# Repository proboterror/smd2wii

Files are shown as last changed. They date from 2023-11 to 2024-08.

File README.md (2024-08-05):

# SMD2Wii
SMD2Wii - adapter for Sega Mega Drive controller to Wii remote.

Adapter emulates Wii Classic Controller with Sega Mega Drive / Genesis 3/6-button controller and can be used with homebrew emulators like Genesis Plus GX and selected Wii Virtual Console Games.<br>
Work not confirmed for NES Classic Mini / SNES Classic Mini.

The goal is to connect SMD 6-button controller to Wii as cheap and simple as possible.<br>
For NES / SNES emulators excellent Nintendo Classic Mini Controller / Nintendo SNES Classic Mini Controller suggested.

Project based on Cluster's [nes2wii](https://github.com/ClusterM/nes2wii) project with following changes:
* Controller replaced with simpler / cheaper ATmega8A
* Deleted all other platforms and second SMD pad support from source code and schematics
* New smaller PCB
* Fixed SMD 6-button pad state query errors
* KiCad 7.0 schematic and PCB sources added

## Schematics

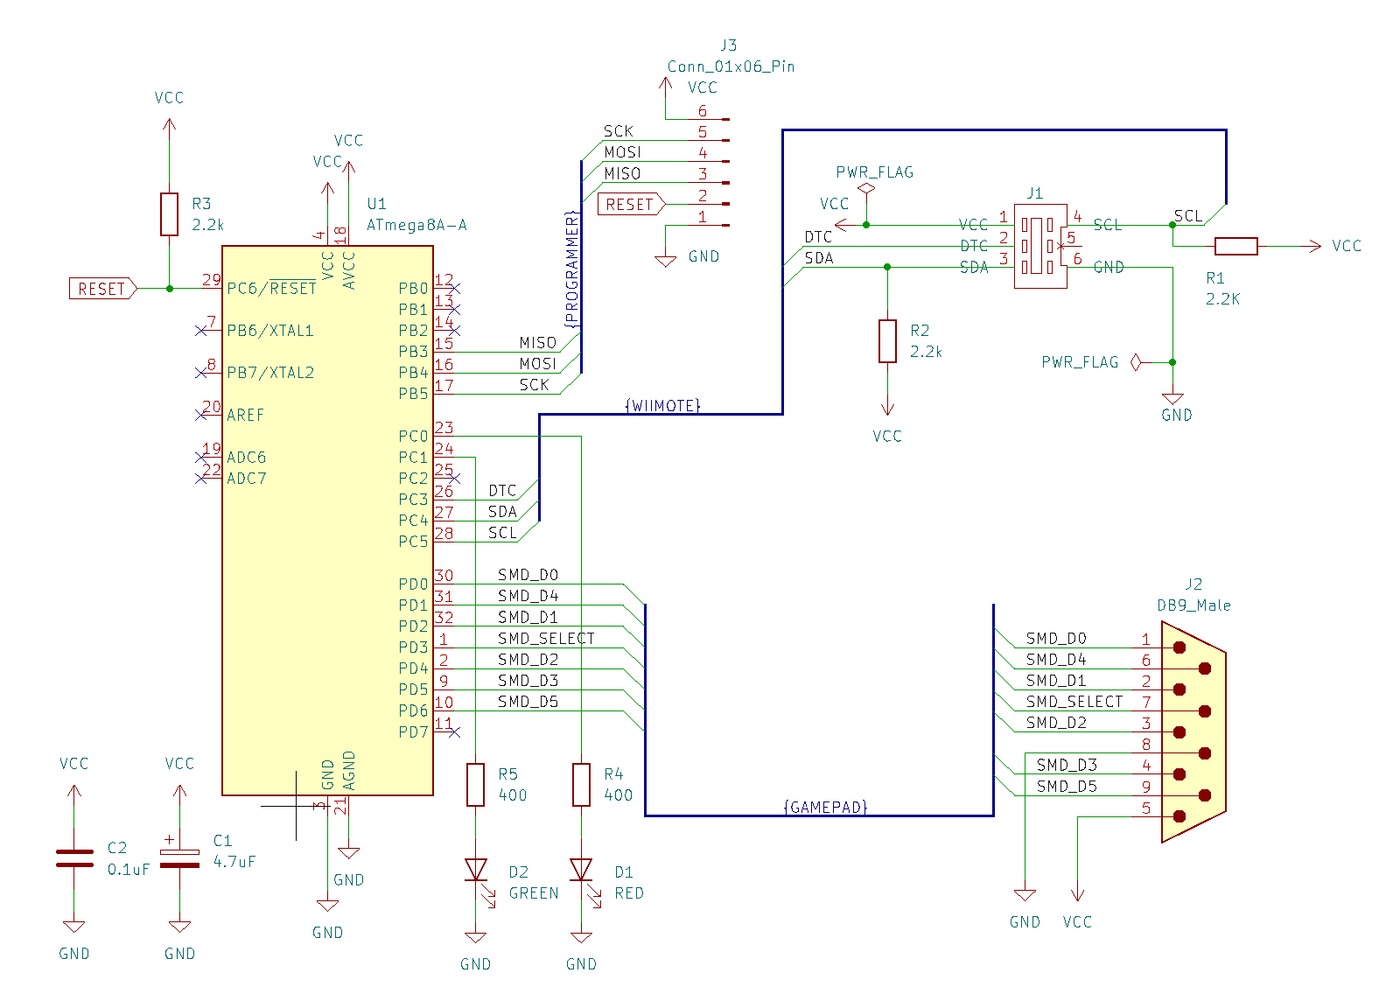
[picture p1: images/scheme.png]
Schematics


Board:<br>
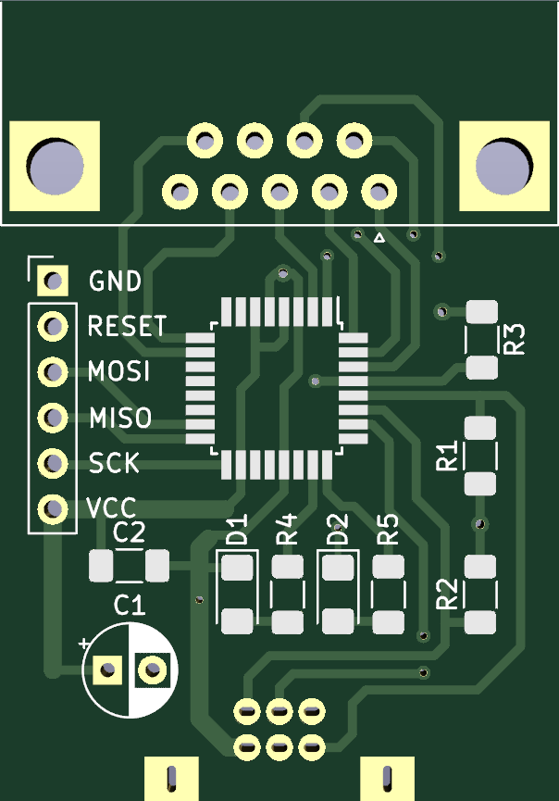
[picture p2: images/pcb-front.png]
Front
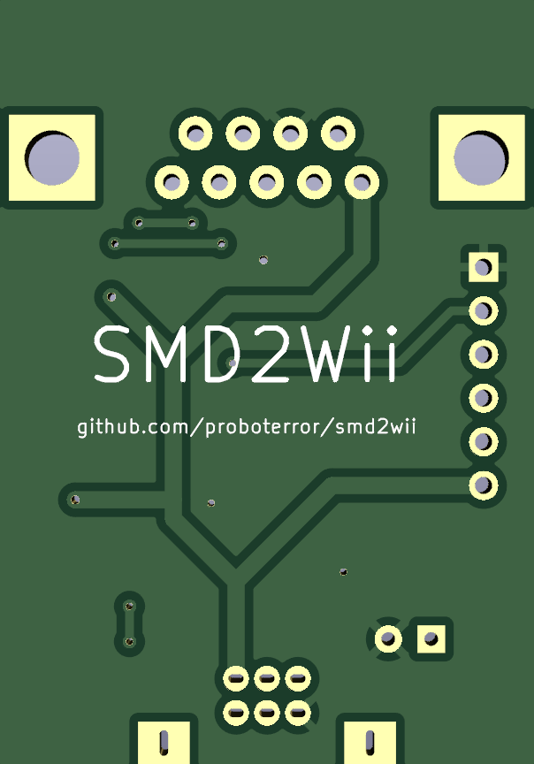
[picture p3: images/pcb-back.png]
Back


Assembled board preview without Wiimote connector:
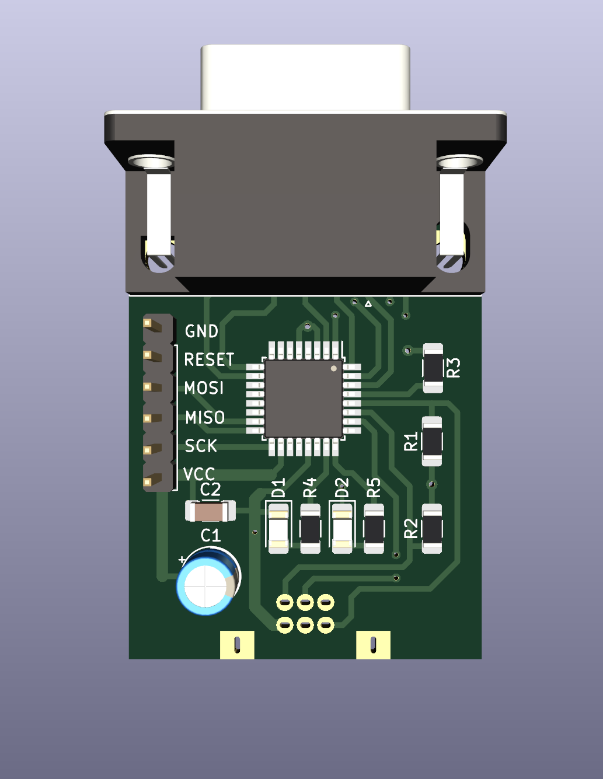
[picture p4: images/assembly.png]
Assembly


## Fuses 

[Bits configuration](images/fuses.png)

* Low fuse: 0xC4
* High fuse: 0xD9

# Compiling from source
Windows:<br>
Install WinAVR-20100110-install.exe<br>
make all<br>

CH341A programmer and NeoProgrammer V2.2 software can be used for firmware .hex flashing.

## Tested with

* ATmega8A-U, 8MHz
* Third party 6-buttons Sega Mega Drive controller with Mode button ("Retro Genesis 16 Bit ACSg11")
* Software: Genesis Plus GX, FCE Ultra GX, WiiMednafen, RetroArch

## Modes

There are three modes for controller d-pad:
* Mode #1 - d-pad works as left analog stick and d-pad on classic controller at the same time
* Mode #2 - d-pad works as left analog stick only
* Mode #3 - d-pad works as d-pad only

Mode 1 selected by default.

You can hold Start+B+C for a few seconds to change mode. Red led will blink 1/2/3 times indicating new mode.

## Bill of materials
* ATMEGA8A-U TQFP32
* DB9 PCB Connector Angle (DSUB-9 Male Horizontal P2.77x2.84mm Edge Pin Offset 7.70mm Mounting Holes Offset 9.12mm)
* Wii controller 6 Pin 90 degree male connector
* SMD 1206 Resistor 2.2k(222) x3
* SMD 1206 Capacitor 0.1(104) uF x1
* (only for programming) Connector PinHeader 2.54mm 1x06 Vertical
* (optional) Electrolytic Capacitor Radial D5.0mm P2.50mm 4.7 uF
* (optional) SMD 1206 Resistor 400 Ohm x2
* (optional) SMD 1206 LED Red x1
* (optional) SMD 1206 LED Green x1

## Notes

### About delays and interrupts
SMD controller polled every 5 ms. Wiimote classic controller query interrupt disabled during the poll (not sure if interrupt is delayed or cancelled).<br>
Worst case scenario additional input delay is about 5-6 ms (or one frame).<br>
Current code:
```c++
void gamepads_query()
{
	_delay_ms(5); // Must be >= 3 to give 6-button controller time to reset

	cli(); // Disable wiimote poll interrupt

	// 8 iterations for read controller state.
	for (b = 0; b < 8; b++)
	{
		_delay_us(2); // Short delay to stabilise outputs in controller.
		...read pad pins
		...invert SELECT pin
	}

	sei(); // Enable interrupt

```
See [gamepads.c](gamepads.c) code comments for more details.
### Buttons mapping
Classic controller to SMD buttons mapping:
```c++
a = smd.c;
b = smd.b;
x = smd.y;
y = smd.a;
l = smd.x;
r = smd.z;
select = smd.mode;
start = smd.start;
```

## Author(s)

Original firmware and schematics for ATMEGA16A:<br>
Alexey 'Cluster' Avdyukhin [https://github.com/ClusterM](https://github.com/ClusterM)<br>
[https://github.com/ClusterM/nes2wii](https://github.com/ClusterM/nes2wii)

Sega MD 6-buttons query code and documentation:<br>
[https://github.com/MickGyver/DaemonBite-Retro-Controllers-USB](https://github.com/MickGyver/DaemonBite-Retro-Controllers-USB)<br>
[https://github.com/jonthysell/SegaController](https://github.com/jonthysell/SegaController)

SMD2Wii modifications:<br>
[probotector](https://github.com/proboterror)

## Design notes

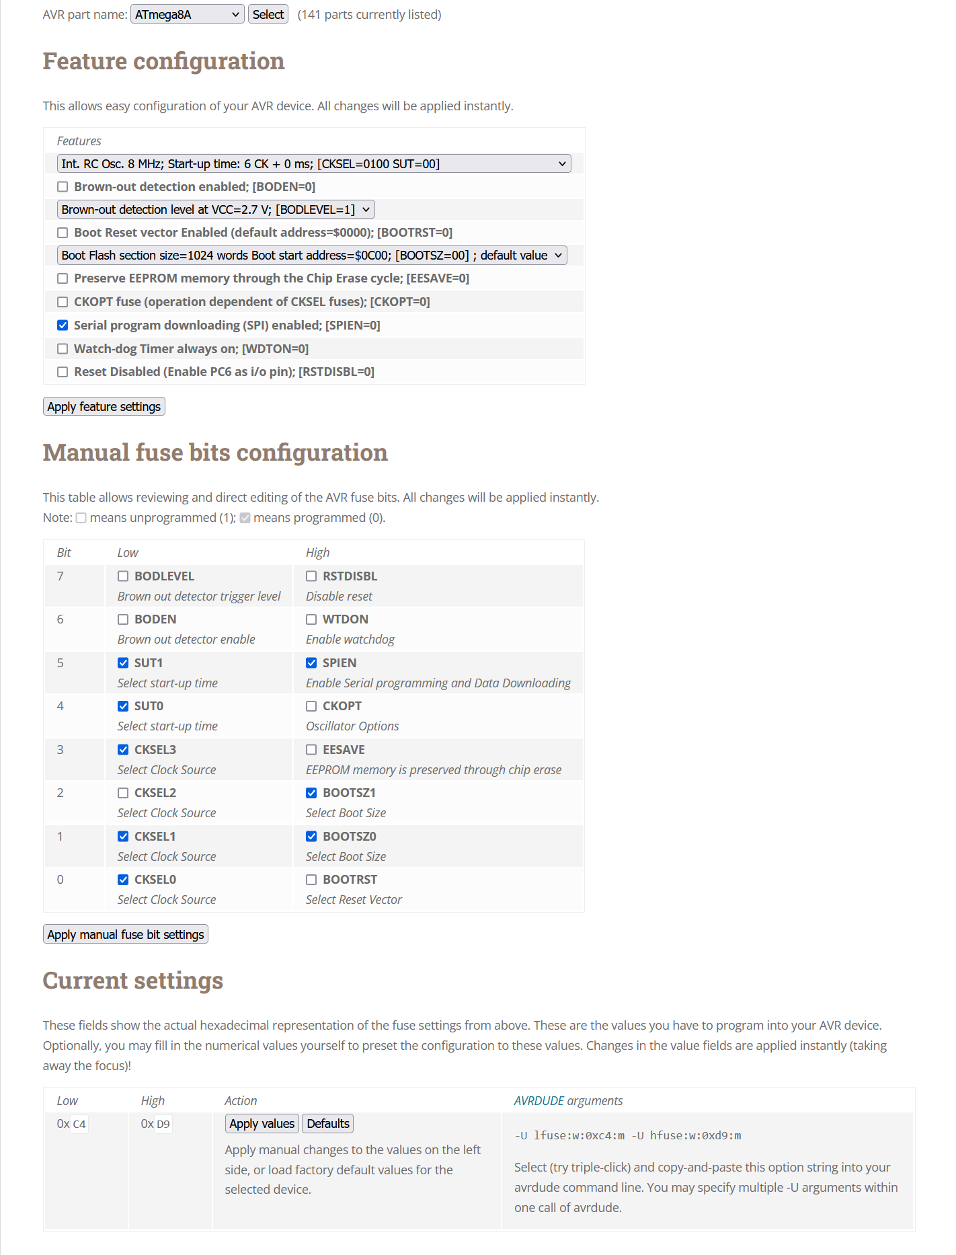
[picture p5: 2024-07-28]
images/fuses.png

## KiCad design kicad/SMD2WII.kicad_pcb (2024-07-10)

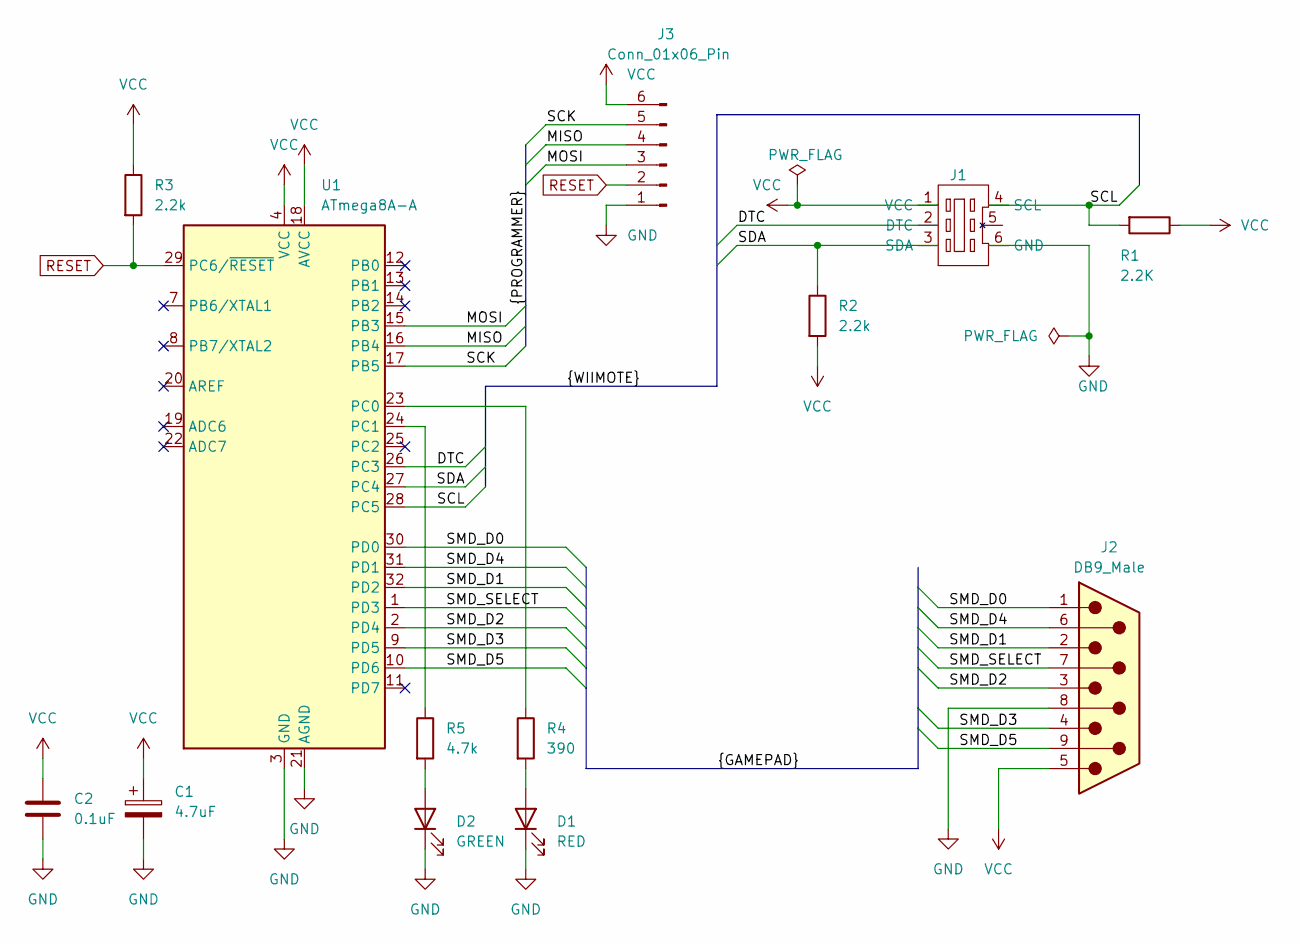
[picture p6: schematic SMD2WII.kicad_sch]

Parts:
C1: 4.7uF; CP_Radial_D5.0mm_P2.50mm
C2: 0.1uF; C_1206_3216Metric_Pad1.33x1.80mm_HandSolder
D1: RED; LED_1206_3216Metric_Pad1.42x1.75mm_HandSolder
D2: GREEN; LED_1206_3216Metric_Pad1.42x1.75mm_HandSolder
J1: Wii_Nunchuck_Connector
J2: DB9_Male; DSUB-9_Male_Horizontal_P2.77x2.84mm_EdgePinOffset7.70mm_Hou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
J3: Conn_01x06_Pin; PinHeader_1x06_P2.54mm_Vertical
R1: 2.2K; R_1206_3216Metric_Pad1.30x1.75mm_HandSolder
R2, R3: 2.2k; R_1206_3216Metric_Pad1.30x1.75mm_HandSolder
R4: 390; R_1206_3216Metric_Pad1.30x1.75mm_HandSolder
R5: 4.7k; R_1206_3216Metric_Pad1.30x1.75mm_HandSolder
U1: ATmega8A-A; TQFP-32_7x7mm_P0.8mm

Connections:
/DTC: J1.2 (DTC), U1.26 (PC3)
/MISO: J3.4, U1.16 (PB4)
/MOSI: J3.3, U1.15 (PB3)
/SCK: J3.5, U1.17 (PB5)
/SCL: J1.4 (SCL), R1.2, U1.28 (PC5)
/SDA: J1.3 (SDA), R2.1, U1.27 (PC4)
/SMD_D0: J2.1, U1.30 (PD0)
/SMD_D1: J2.2, U1.32 (PD2)
/SMD_D2: J2.3, U1.2 (PD4)
/SMD_D3: J2.4, U1.9 (PD5)
/SMD_D4: J2.6, U1.31 (PD1)
/SMD_D5: J2.9, U1.10 (PD6)
/SMD_SELECT: J2.7, U1.1 (PD3)
GND: C1.2, C2.2, D1.1 (K), D2.1 (K), J1.6 (GND), J2.8, J3.1, U1.3 (GND), U1.5 (GND), U1.21 (AGND)
unnamed: D1.2 (A), R4.2
unnamed: D2.2 (A), R5.2
unnamed: R4.1, U1.23 (PC0)
unnamed: R5.1, U1.24 (PC1)
RESET: J3.2, R3.2, U1.29 (PC6/~RESET)
VCC: C1.1, C2.1, J1.1 (VCC), J2.5, J3.6, R1.1, R2.2, R3.1, U1.4 (VCC), U1.6 (VCC), U1.18 (AVCC)

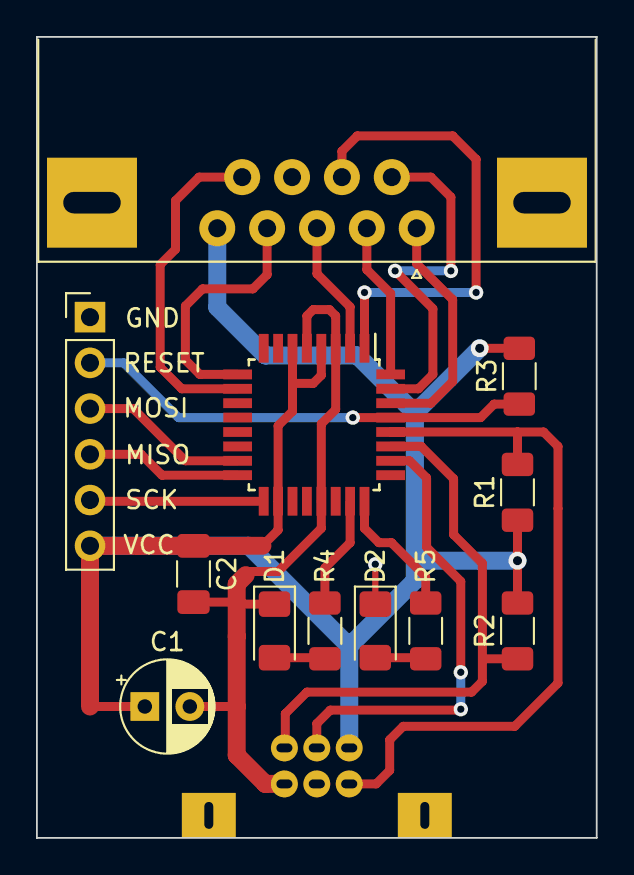
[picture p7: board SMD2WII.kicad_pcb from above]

Board: 2 copper layers, 31.1 x 44.5 mm, 13 parts (0 on the bottom side), 20 nets.

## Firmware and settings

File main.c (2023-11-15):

#include "nes2wii.h"
#include "defines.h"
#include <util/delay.h>
#include <avr/eeprom.h>
#include <avr/wdt.h>
#include <inttypes.h>
#include "wiimote.h"
#include "gamepads.h"

// classic controller id
const unsigned char classic_controller_id[6] = {0x00, 0x00, 0xA4, 0x20, 0x01, 0x01};

volatile int8_t jx = 0, jy = 0, rx = 0, ry = 0;
volatile uint8_t tl = 0, tr = 0;
volatile uint8_t left = 0, right = 0, up = 0, down = 0, a = 0, b = 0, x = 0, y = 0, 
				select = 0, start = 0, home = 0, l = 0, r = 0, zl = 0, zr = 0;
volatile uint8_t connected = 0;
volatile uint8_t dpad_mode = DPAD_MODE_BOTH;

// calibration data
const unsigned char cal_data[32] = {
	0x00, 0x00, 0x00, 0x00,
	0x00, 0x00, 0x00, 0x00,
	0x00, 0x00, 0x00, 0x00,
	0x00, 0x00, 0x00, 0x00,
	0x00, 0x00, 0x00, 0x00,
	0x00, 0x00, 0x00, 0x00,
	0x00, 0x00, 0x00, 0x00,
	0x00, 0x00, 0x00, 0x00
};

void wiimote_query()
{
	wdt_reset();
	if (connected < 2)
	{
		connected = 2;
		RED_ON;
	}
	unsigned char but_dat[8]; // struct containing button data
	if (twi_reg[0xFE] == 1) // data format
	{
		but_dat[0] = 0b00000000; // RX<4:3>	LX<5:0>
		but_dat[1] = 0b00000000; // RX<2:1>	LY<5:0>
		but_dat[2] = 0b00000000; // RX<0>	LT<4:3>	RY<4:0>
		but_dat[3] = 0b00000000; // LT<2:0>	RT<4:0>
		but_dat[4] = 0b11111111; // BDR	BDD	BLT	B-	BH	B+	BRT	 1
		but_dat[5] = 0b11111111; // BZL	BB	BY	BA	BX	BZR	BDL	BDU
		but_dat[6] = 0;
		but_dat[7] = 0;
		
		but_dat[0] |= (jx / 4 + 0x20) & 0x3F;
		but_dat[1] |= (jy / -4 + 0x20) & 0x3F;
		but_dat[0] |= ((rx / 8 + 0x10) & 0x18) << 3;
		but_dat[1] |= ((rx / 8 + 0x10) & 0x06) << 5;
		but_dat[2] |= ((rx / 8 + 0x10) & 0x01) << 7;
		but_dat[2] |= (ry / -8 + 0x10) & 0x1F;
		but_dat[2] |= ((tl / 8) & 0x18) << 2;
		but_dat[3] |= ((tl / 8) & 0x07) << 5;
		but_dat[3] |= (tr / 8) & 0x1F;

		if (right) but_dat[4] &= ~(1<<7);
		if (down) but_dat[4] &= ~(1<<6);
		if (l) but_dat[4] &= ~(1<<5);
		if (select) but_dat[4] &= ~(1<<4);
		if (home) but_dat[4] &= ~(1<<3);
		if (start) but_dat[4] &= ~(1<<2);
		if (r) but_dat[4] &= ~(1<<1);
		
		if (zl) but_dat[5] &= ~(1<<7);
		if (b) but_dat[5] &= ~(1<<6);
		if (y) but_dat[5] &= ~(1<<5);
		if (a) but_dat[5] &= ~(1<<4);
		if (x) but_dat[5] &= ~(1<<3);
		if (zr) but_dat[5] &= ~(1<<2);
		if (left) but_dat[5] &= ~(1<<1);
		if (up) but_dat[5] &= ~(1<<0);
		
		but_dat[6] = 0;
		but_dat[7] = 0;
		
		if (((but_dat[4] & 0xFE) == 0xFE) && (but_dat[5] == 0xFF) && 
			(ABS(jx) < DEAD_ZONE) && (ABS(jy) < DEAD_ZONE) &&
			(ABS(rx) < DEAD_ZONE) && (ABS(ry) < DEAD_ZONE))
			GREEN_OFF;
		else
			GREEN_ON;
		
		wm_newaction(but_dat);
	} 
	else if (twi_reg[0xFE] == 3) // data format
	{
		but_dat[0] = jx + 0x80;
		but_dat[1] = rx + 0x80;
		but_dat[2] = 0x7fl - jy;
		but_dat[3] = 0x7fl - ry;
		but_dat[4] = tl;
		but_dat[5] = tr;
			
		but_dat[6] = 0b11111111; // BDR	BDD	BLT	B-	BH	B+	BRT	 1
		but_dat[7] = 0b11111111; // BZL	BB	BY	BA	BX	BZR	BDL	BDU
			
		if (right) but_dat[6] &= ~(1<<7);
		if (down) but_dat[6] &= ~(1<<6);
		if (l) but_dat[6] &= ~(1<<5);
		if (select) but_dat[6] &= ~(1<<4);
		if (home) but_dat[6] &= ~(1<<3);
		if (start) but_dat[6] &= ~(1<<2);
		if (r) but_dat[6] &= ~(1<<1);

		if (zl) but_dat[7] &= ~(1<<7);
		if (b) but_dat[7] &= ~(1<<6);
		if (y) but_dat[7] &= ~(1<<5);
		if (a) but_dat[7] &= ~(1<<4);
		if (x) but_dat[7] &= ~(1<<3);
		if (zr) but_dat[7] &= ~(1<<2);
		if (left) but_dat[7] &= ~(1<<1);
		if (up) but_dat[7] &= ~(1<<0);

		if (((but_dat[6] & 0xFE) == 0xFE) && (but_dat[7] == 0xFF) &&
			(ABS(jx) < DEAD_ZONE) && (ABS(jy) < DEAD_ZONE) &&
			(ABS(rx) < DEAD_ZONE) && (ABS(ry) < DEAD_ZONE))
			GREEN_OFF;
		else
			GREEN_ON;

		wm_newaction(but_dat);
	} 
}

int main()
{
	RED_OFF;
	GREEN_OFF;
	RED_LED_PORT_DDR |= (1<<RED_LED_PIN); // Red led, output
	GREEN_LED_PORT_DDR |= (1<<GREEN_LED_PIN); // Red led, output
	gamepads_init();
	dpad_mode = eeprom_read_byte((void*)0); // current mode
	if (dpad_mode > 2) dpad_mode = DPAD_MODE_BOTH;

	wm_init((void*)classic_controller_id, (void*)cal_data, wiimote_query);
	connected = 1;
	wdt_enable(WDTO_2S);

	while(1)
	{
		if (connected == 2)
		{
			connected = 3;
		}

		gamepads_query();

		a = smd1.c;
		b = smd1.b;
		x = smd1.y;
		y = smd1.a;
		l = smd1.x;
		r = smd1.z;
		select = smd1.mode;
		start = smd1.start;
		zl = 0;
		zr = 0;

		uint8_t tmp_up = 0;
		uint8_t tmp_down = 0;
		uint8_t tmp_left = 0;
		uint8_t tmp_right = 0;
		if (dpad_mode == DPAD_MODE_BOTH || dpad_mode == DPAD_MODE_DPAD)
		{
			tmp_up |= smd1.up;
			tmp_down |= smd1.down;
			tmp_left |= smd1.left;
			tmp_right |= smd1.right;
		}
		up = tmp_up;
		down = tmp_down;
		left = tmp_left;
		right = tmp_right;

		int temp_jx = 0;
		int temp_jy = 0;
		int temp_rx = 0;
		int temp_ry = 0;
		if (dpad_mode == DPAD_MODE_BOTH || dpad_mode == DPAD_MODE_STICK)
		{
			if (smd1.up)
				temp_jy = -127;
			if (smd1.down)
				temp_jy = 127;
			if (smd1.left)
				temp_jx = -127;
			if (smd1.right)
				temp_jx = 127;
		}

		jx = temp_jx;
		jy = temp_jy;
		rx = temp_rx;
		ry = temp_ry;

		// Need to switch mode? Hold Start+A+B for a second
		static uint16_t time = 0;
		if (start && a && b)
		{
			time++;
			if (time >= 500)
			{
				dpad_mode = (dpad_mode+1) % 3;
				eeprom_write_byte((void*)0, dpad_mode);
				RED_OFF;
				_delay_ms(1000);
				uint8_t i;
				for (i = 0; i <= dpad_mode; i++)
				{
					RED_ON;
					_delay_ms(200);
					RED_OFF;
					_delay_ms(200);
				}
				wdt_enable(WDTO_500MS);
				cli();
				while(1); // restart
			}
		} else time = 0;
	}
	return 0;
}

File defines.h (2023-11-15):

#pragma once

//#define F_CPU 8000000L

#define TWI_PORT C
#define TWI_SCL_PIN 5
#define TWI_SDA_PIN 4

#define DETECT_PORT C
#define DETECT_PIN 3

#define SMD_SELECT_PORT D
#define SMD_SELECT_PIN 3
#define SMD1_DATA_PORT D
#define SMD1_DATA_PIN0 0
#define SMD1_DATA_PIN1 2
#define SMD1_DATA_PIN2 4
#define SMD1_DATA_PIN3 5
#define SMD1_DATA_PIN4 1
#define SMD1_DATA_PIN5 6

#define RED_LED_PORT C
#define RED_LED_PIN 0
#define GREEN_LED_PORT C
#define GREEN_LED_PIN 1

#define DEAD_ZONE 32

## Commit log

2023-11-15 Fixed 6-buttons SMD gamepad query gliches: wiimote state query interrups breaks SMD 6-button controller state read timings, so disable interrupts before read cycle.
2023-11-15 Set target controller to ATmega8. Set CPU speed to 8 MHZ.
    Controller fuses:
    * Low fuse: 0xC4
    * High fuse: 0xD9
    Correct pins and ports defines according to new scheme.
    Optimize compiler code for size.
    Note: compiler does not calculate bit operations with constants in compile time.
    [defines.h]
2023-11-15 Replace include guards with pragma once. Delete unused macro.
    [defines.h, nes2wii.h]
2023-11-15 Add KiCad 7 schematic and pcb source.
    [SMD2WII.kicad_pcb, SMD2WII.kicad_sch]
2023-11-15 Add Gerber files for pcb manufacturing.
    [SMD2WII-B_Cu.gbr, SMD2WII-B_Mask.gbr, SMD2WII-B_Paste.gbr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]
2023-12-15 Swap MISO <=> MOSI.
    [SMD2WII-B_Cu.gbr, SMD2WII-B_Mask.gbr, SMD2WII-B_Paste.gbr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]
2023-12-16 Connect RESET to VCC instead of GND.
    [SMD2WII-B_Cu.gbr, SMD2WII-B_Mask.gbr, SMD2WII-B_Paste.gbr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]
2023-12-18 Compact PCB.
    [SMD2WII-B_Cu.gbr, SMD2WII-B_Mask.gbr, SMD2WII-B_Paste.gbr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]
2023-12-20 Re-use C1 pin for front side GND.
    [SMD2WII-B_Cu.gbr, SMD2WII-B_Mask.gbr, SMD2WII-B_Paste.gbr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]
2023-12-24 Revert "Set d-pad mode as d-pad only by default."
    This reverts commit 5238fb1d97f34cc982e6786cec14f2f01e515b09.
    [main.c]
2023-12-24 Correct description for switch mode buttons.
2024-01-27 PCB confirmed working. Improved position of decoupling capacitor on PCB. Resistor value for green LED changed from 400 Ohm to 4.7k (YMMV).
    [SMD2WII.kicad_pcb, SMD2WII.kicad_sch]
2024-07-10 DSUB-9 connector oval mounting holes.
    [SMD2WII-B_Cu.gbr, SMD2WII-B_Mask.gbr, SMD2WII-B_Paste.gbr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]
2024-07-28 Add fuse bits configuration screenshot.
2024-07-28 Error fixed: UP press registers as UP + Z with 3V power. Enable 2 us delay after SELECT signal change before controller data read according to Genesis Software Manual.
